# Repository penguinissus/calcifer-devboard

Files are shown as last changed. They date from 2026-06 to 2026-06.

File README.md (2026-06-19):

# Calcifer Devboard
Calcifer Devboard is a funny take on the RP2040 Devboard. It contains all of the basic components of what a devboard usually has like SRAM, processors, USB controllers, and breakout pins. The interesting twist on this devboard is that it is shaped like Calcifer, a character from Howl's Moving Castle.  
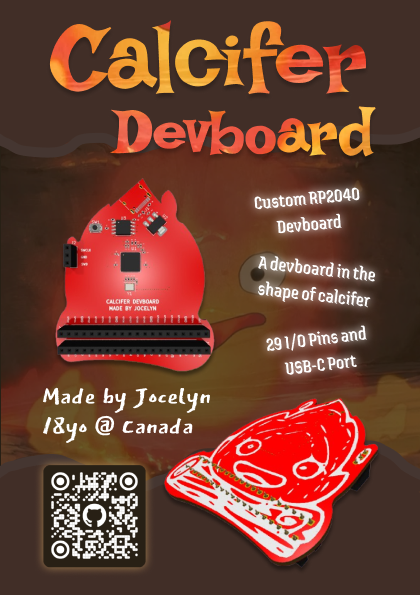
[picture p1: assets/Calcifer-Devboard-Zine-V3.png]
Zine
   

# Features
- USB-C Port  
- 12MHz Crystal Oscillator  
- 16mb Flash Storage
- 29 I/O Pins  

# Why did I make it
If you don't know the story behind Howl's Moving Castle, Calcifer is a fire demon that is trapped inside Howl's Castle and he powers and controls all of the magical things that the castle does. To me, this seemed parallel to what a devboard does in any electronics project, since a devboard is basically the heart and soul and would control all of the other components around it. 

# Diagrams
This schematic diagram looks the exact same as the guide from kaipereira.  
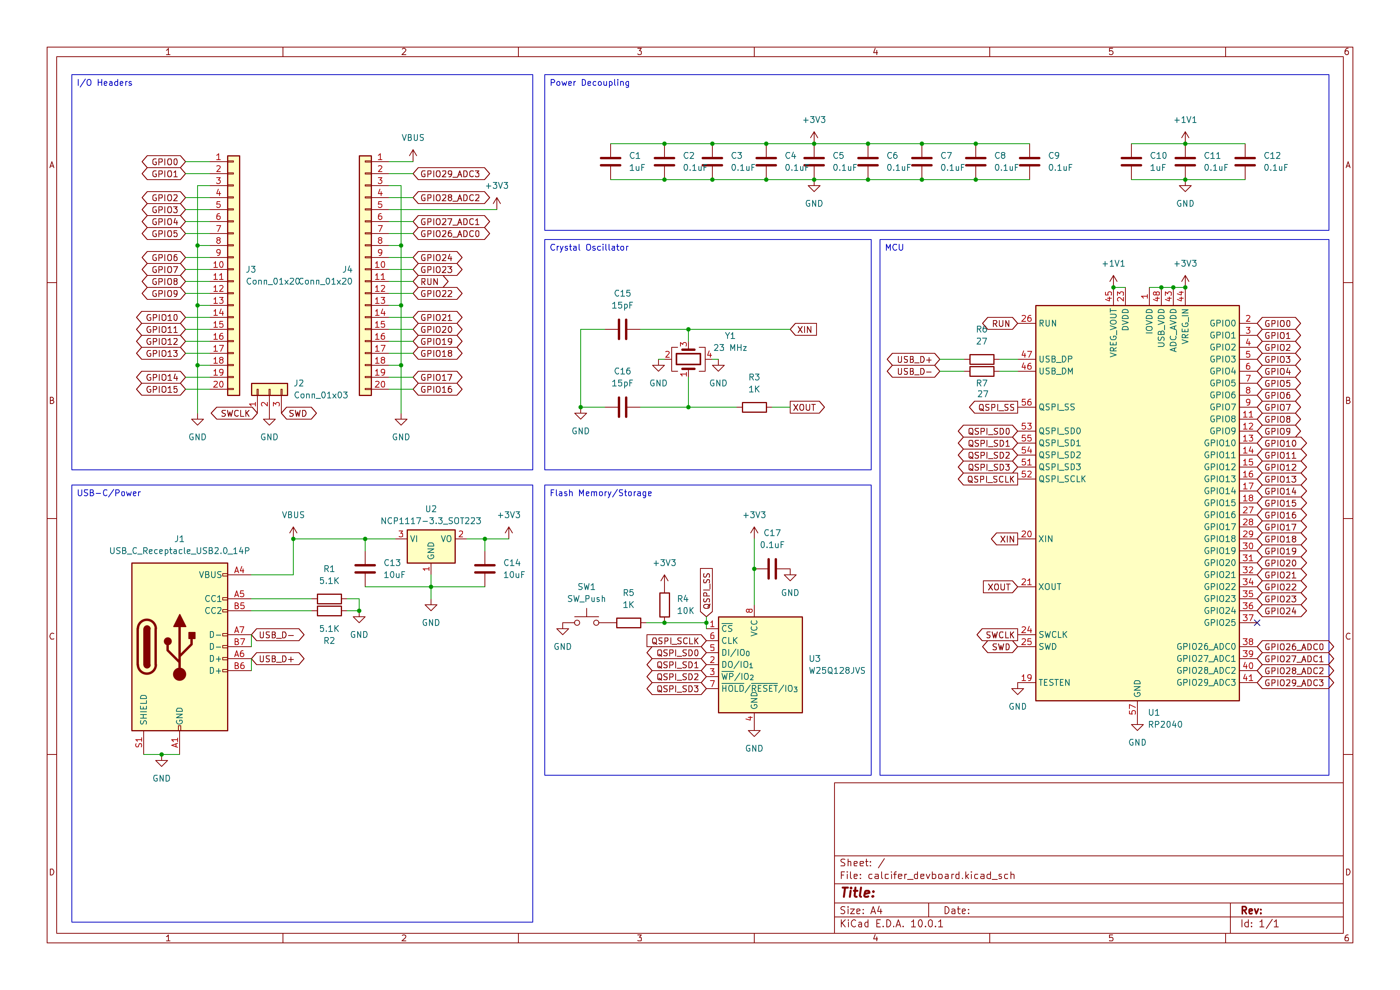
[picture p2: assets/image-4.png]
Schematic Diagram
  
This is what my devboard looked like in the PCB editor. You can see that it has the outline and silkscreen of calcifer on it.  
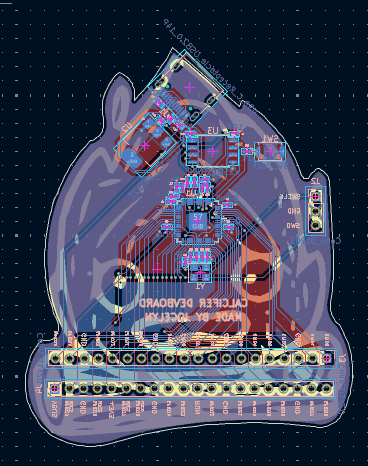
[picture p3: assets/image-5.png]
PCB Editor View
  
This is what the front of the PCB should look like when it is built properly. The frontside only shows a silkscreen of calcifer and is not obstructed by any components.  
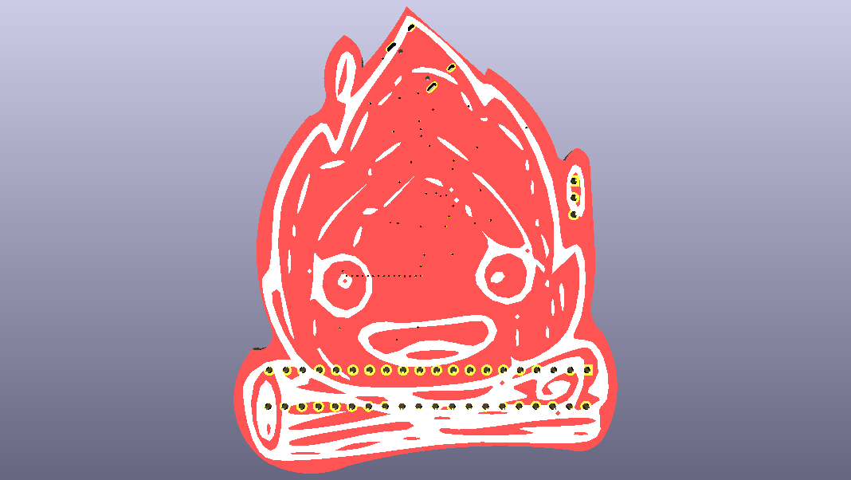
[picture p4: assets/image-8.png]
3D Model Front View
  
This is what the back of the PCB should look like. All of the components are on this side and all of the pins are clearly labeled. There is also a label saying this is made by me.  
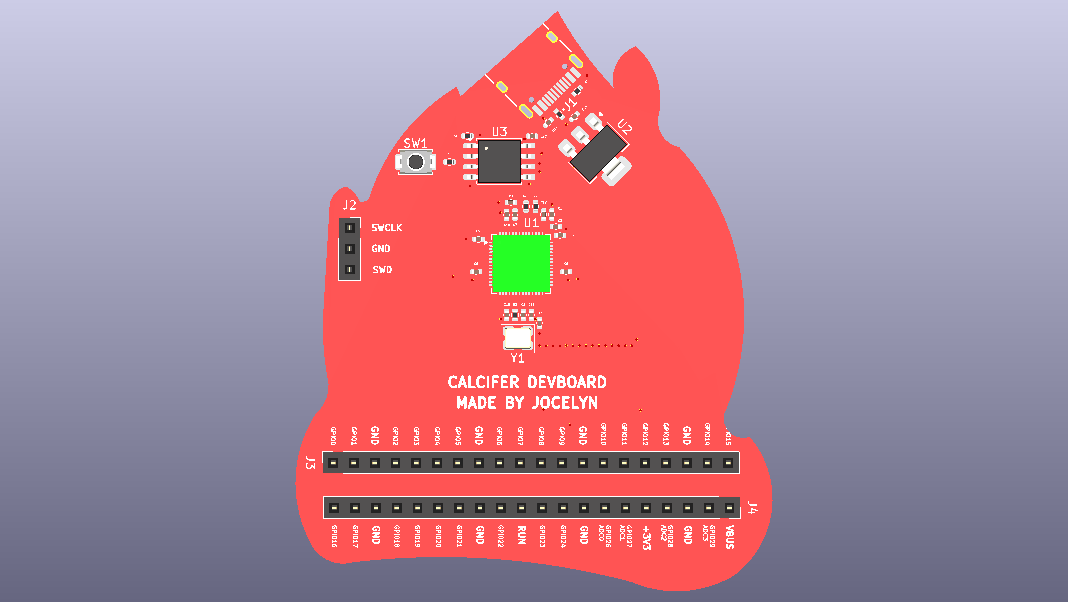
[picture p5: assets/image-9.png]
3D Model Back View
  

# Resource
This project is all thanks to [kaipereira's guide](https://github.com/KaiPereira/build-a-devboard/blob/master/README.md) on designing an RP2040 devboard. 

# How to use
This is just a devboard so there isn't really a step-by-step assembly or firmware isntructions.

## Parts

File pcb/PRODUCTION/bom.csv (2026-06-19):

Designator | Footprint | Quantity | Value | LCSC Part #
C1, C10 | 0402 | 2 | 1uF
C11, C12, C17, C2, C3, C4, C5, C6, C7, C8, C9 | 0402 | 11 | 0.1uF
C13, C14 | 0402 | 2 | 10uF
C15, C16 | 0402 | 2 | 15pF
J1 | USB_C_Receptacle_HRO_TYPE-C-31-M-12 | 1 | USB_C_Receptacle_USB2.0_14P
J2 | PinSocket_1x03_P2.54mm_Vertical | 1 | Conn_01x03
J3, J4 | PinSocket_1x20_P2.54mm_Vertical | 2 | Conn_01x20
R1, R2 | 0402 | 2 | 5.1K
R3, R5 | 0402 | 2 | 1K
R4 | 0402 | 1 | 10K
R6, R7 | 0402 | 2 | 27
SW1 | SW_Push_SPST_NO_Alps_SKRK | 1 | SW_Push
U1 | QFN-56-1EP_7x7mm_P0.4mm_EP3.2x3.2mm | 1 | RP2040
U2 | SOT-223-3_TabPin2 | 1 | NCP1117-3.3_SOT223
U3 | SOIC-8_5.3x5.3mm_P1.27mm | 1 | W25Q128JVS
Y1 | Crystal_SMD_3225-4Pin_3.2x2.5mm | 1 | 23 MHz

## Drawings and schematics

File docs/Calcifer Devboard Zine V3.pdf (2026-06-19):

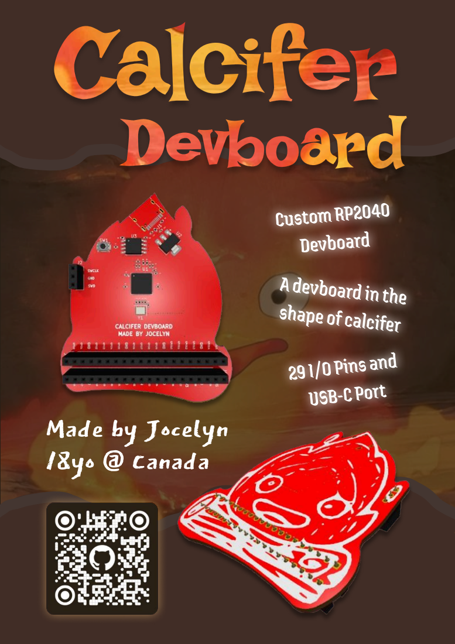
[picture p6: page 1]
Custom RP2040; Devboard; 29 I/O Pins and; USB-C Port

A devboard in the

shape of calcifer

Made by Jocelyn
18yo @ Canada

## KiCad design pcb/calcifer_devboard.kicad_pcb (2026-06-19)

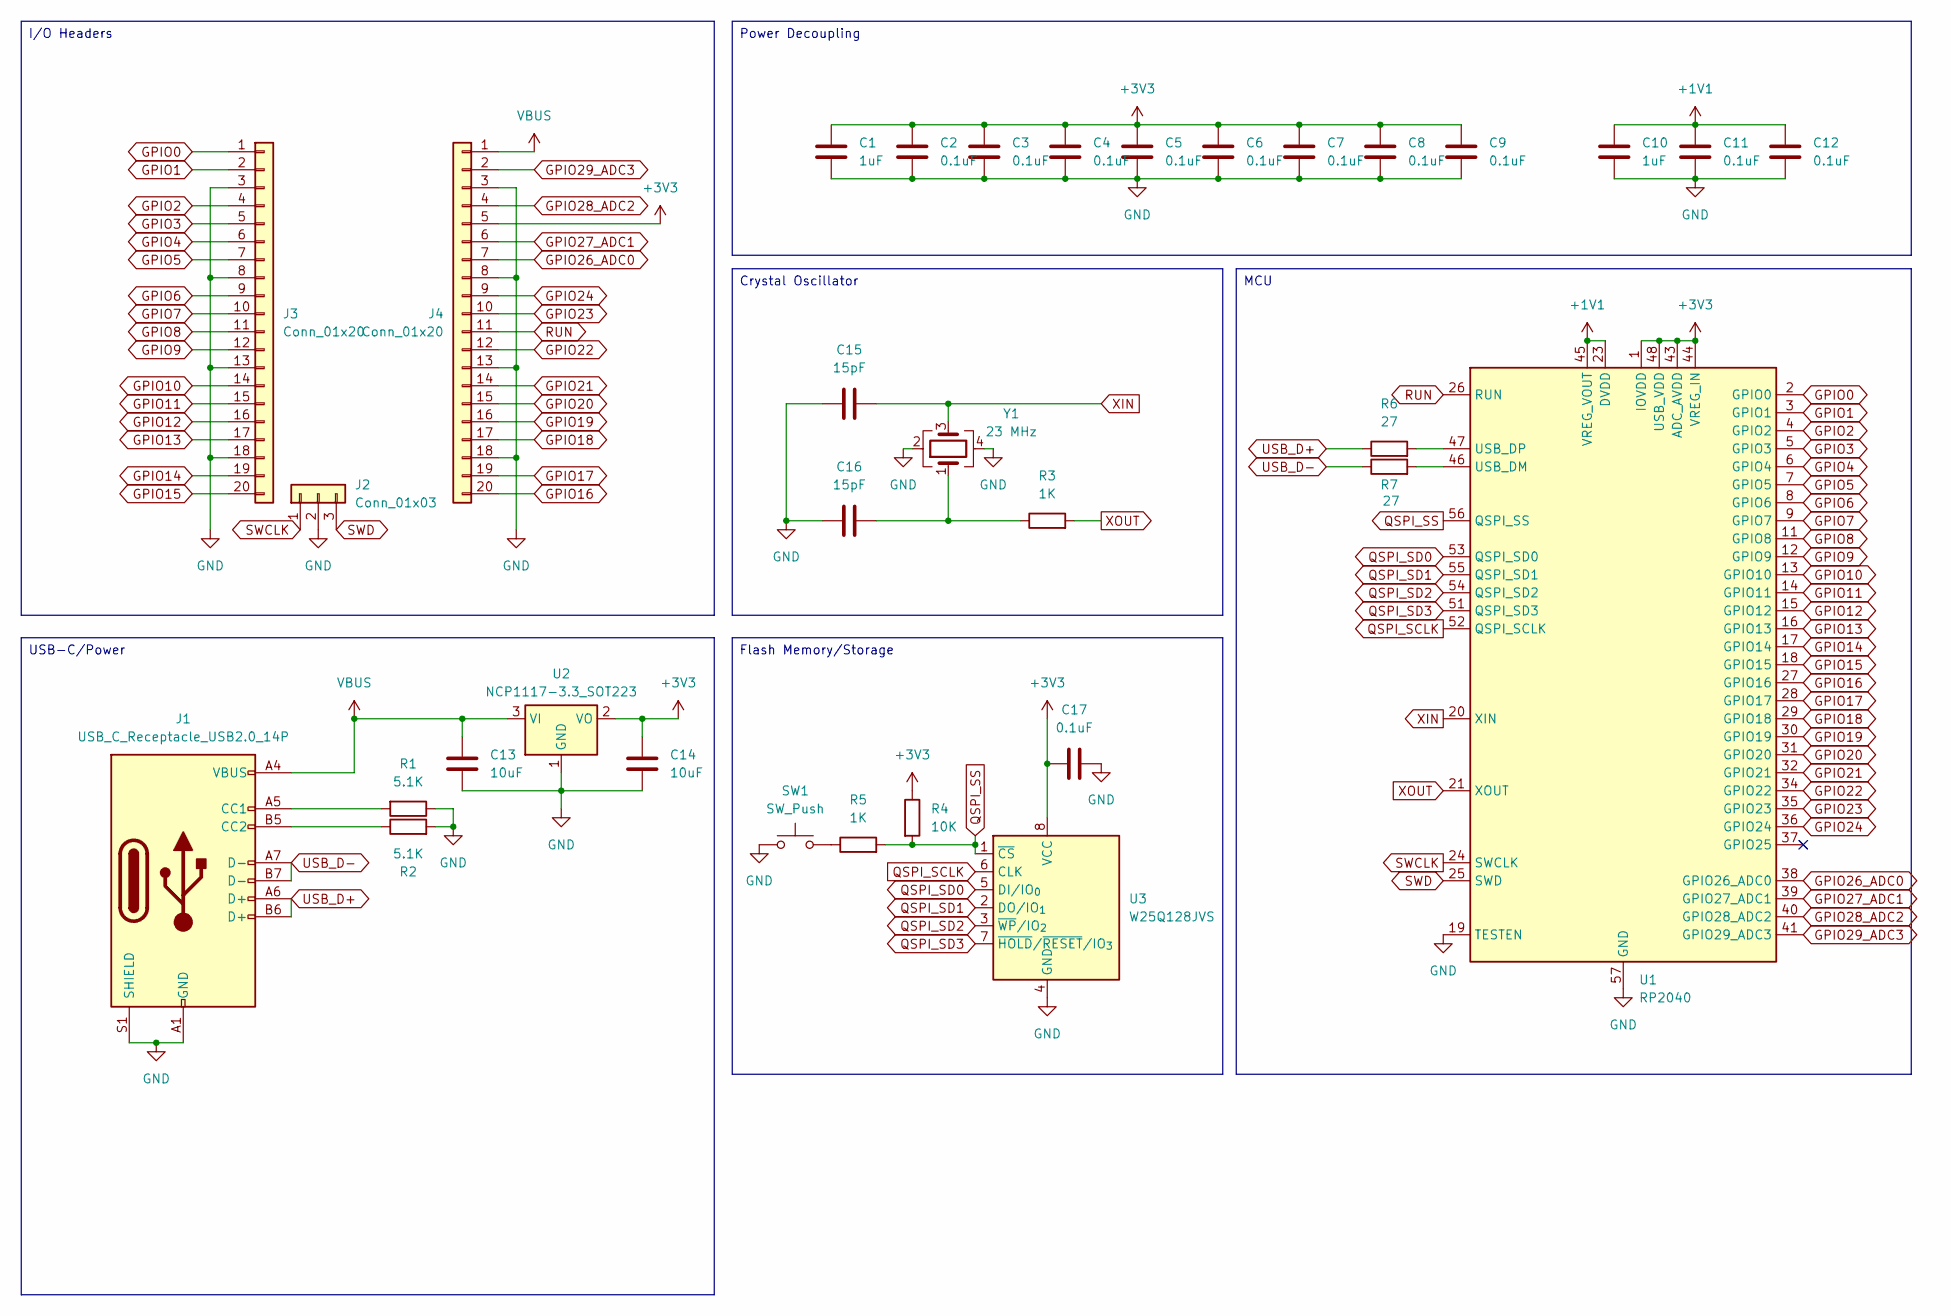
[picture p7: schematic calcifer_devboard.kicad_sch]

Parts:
C1, C10: 1uF; C_0402_1005Metric
C2, C3, C4, C5, C6, C7, C8, C9, C11, C12, C17: 0.1uF; C_0402_1005Metric
C13, C14: 10uF; C_0402_1005Metric
C15, C16: 15pF; C_0402_1005Metric
J1: USB_C_Receptacle_USB2.0_14P; USB_C_Receptacle_HRO_TYPE-C-31-M-12
J2: Conn_01x03; PinSocket_1x03_P2.54mm_Vertical
J3, J4: Conn_01x20; PinSocket_1x20_P2.54mm_Vertical
R1, R2: 5.1K; R_0402_1005Metric
R3, R5: 1K; R_0402_1005Metric
R4: 10K; R_0402_1005Metric
R6, R7: 27; R_0402_1005Metric
SW1: SW_Push; SW_Push_SPST_NO_Alps_SKRK
U1: RP2040; QFN-56-1EP_7x7mm_P0.4mm_EP3.2x3.2mm
U2: NCP1117-3.3_SOT223; SOT-223-3_TabPin2
U3: W25Q128JVS; SOIC-8_5.3x5.3mm_P1.27mm
Y1: 23 MHz; Crystal_SMD_3225-4Pin_3.2x2.5mm

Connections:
+1V1: C10.1, C11.1, C12.1, U1.23 (DVDD), U1.45 (VREG_VOUT), U1.50 (DVDD)
+3V3: C1.1, C2.1, C3.1, C4.1, C5.1, C6.1, C7.1, C8.1, C9.1, C14.1, C17.2, J4.5, R4.1, U1.1 (IOVDD), U1.10 (IOVDD), U1.22 (IOVDD), U1.33 (IOVDD), U1.42 (IOVDD), U1.43 (ADC_AVDD), U1.44 (VREG_IN), U1.48 (USB_VDD), U1.49 (IOVDD), U2.2 (VO), U3.8 (VCC)
GND: C1.2, C2.2, C3.2, C4.2, C5.2, C6.2, C7.2, C8.2, C9.2, C10.2, C11.2, C12.2, C13.2, C14.2, C15.1, C16.2, C17.1, J1.A1 (GND), J1.A12 (GND), J1.B1 (GND), J1.B12 (GND), J1.S1 (SHIELD), J2.2, J3.3, J3.8, J3.13, J3.18, J4.3, J4.8, J4.13, J4.18, R1.1, R2.2, SW1.1, U1.19 (TESTEN), U1.57 (GND), U2.1 (GND), U3.4 (GND), Y1.2, Y1.4
GPIO0: J3.1, U1.2 (GPIO0)
GPIO1: J3.2, U1.3 (GPIO1)
GPIO2: J3.4, U1.4 (GPIO2)
GPIO3: J3.5, U1.5 (GPIO3)
GPIO4: J3.6, U1.6 (GPIO4)
GPIO5: J3.7, U1.7 (GPIO5)
GPIO6: J3.9, U1.8 (GPIO6)
GPIO7: J3.10, U1.9 (GPIO7)
GPIO8: J3.11, U1.11 (GPIO8)
GPIO9: J3.12, U1.12 (GPIO9)
GPIO10: J3.14, U1.13 (GPIO10)
GPIO11: J3.15, U1.14 (GPIO11)
GPIO12: J3.16, U1.15 (GPIO12)
GPIO13: J3.17, U1.16 (GPIO13)
GPIO14: J3.19, U1.17 (GPIO14)
GPIO15: J3.20, U1.18 (GPIO15)
GPIO16: J4.20, U1.27 (GPIO16)
GPIO17: J4.19, U1.28 (GPIO17)
GPIO18: J4.17, U1.29 (GPIO18)
GPIO19: J4.16, U1.30 (GPIO19)
GPIO20: J4.15, U1.31 (GPIO20)
GPIO21: J4.14, U1.32 (GPIO21)
GPIO22: J4.12, U1.34 (GPIO22)
GPIO23: J4.10, U1.35 (GPIO23)
GPIO24: J4.9, U1.36 (GPIO24)
GPIO26_ADC0: J4.7, U1.38 (GPIO26_ADC0)
GPIO27_ADC1: J4.6, U1.39 (GPIO27_ADC1)
GPIO28_ADC2: J4.4, U1.40 (GPIO28_ADC2)
GPIO29_ADC3: J4.2, U1.41 (GPIO29_ADC3)
unnamed: C16.1, R3.1, Y1.1
unnamed: J1.A5 (CC1), R1.2
unnamed: J1.B5 (CC2), R2.1
unnamed: R5.1, SW1.2
unnamed: R7.2, U1.46 (USB_DM)
unnamed: R6.2, U1.47 (USB_DP)
QSPI_SCLK: U1.52 (QSPI_SCLK), U3.6 (CLK)
QSPI_SD0: U1.53 (QSPI_SD0), U3.5 (DI/IO_{0})
QSPI_SD1: U1.55 (QSPI_SD1), U3.2 (DO/IO_{1})
QSPI_SD2: U1.54 (QSPI_SD2), U3.3 (~WP/IO_{2})
QSPI_SD3: U1.51 (QSPI_SD3), U3.7 (~HOLD/~RESET/IO_{3})
QSPI_SS: R4.2, R5.2, U1.56 (QSPI_SS), U3.1 (~CS)
RUN: J4.11, U1.26 (RUN)
SWCLK: J2.1, U1.24 (SWCLK)
SWD: J2.3, U1.25 (SWD)
USB_D+: J1.A6 (D+), J1.B6 (D+), R6.1
USB_D-: J1.A7 (D-), J1.B7 (D-), R7.1
VBUS: C13.1, J1.A4 (VBUS), J1.A9 (VBUS), J1.B4 (VBUS), J1.B9 (VBUS), J4.1, U2.3 (VI)
XIN: C15.2, U1.20 (XIN), Y1.3
XOUT: R3.2, U1.21 (XOUT)

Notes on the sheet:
Flash Memory/Storage
Power Decoupling
I/O Headers
Crystal Oscillator
USB-C/Power
MCU

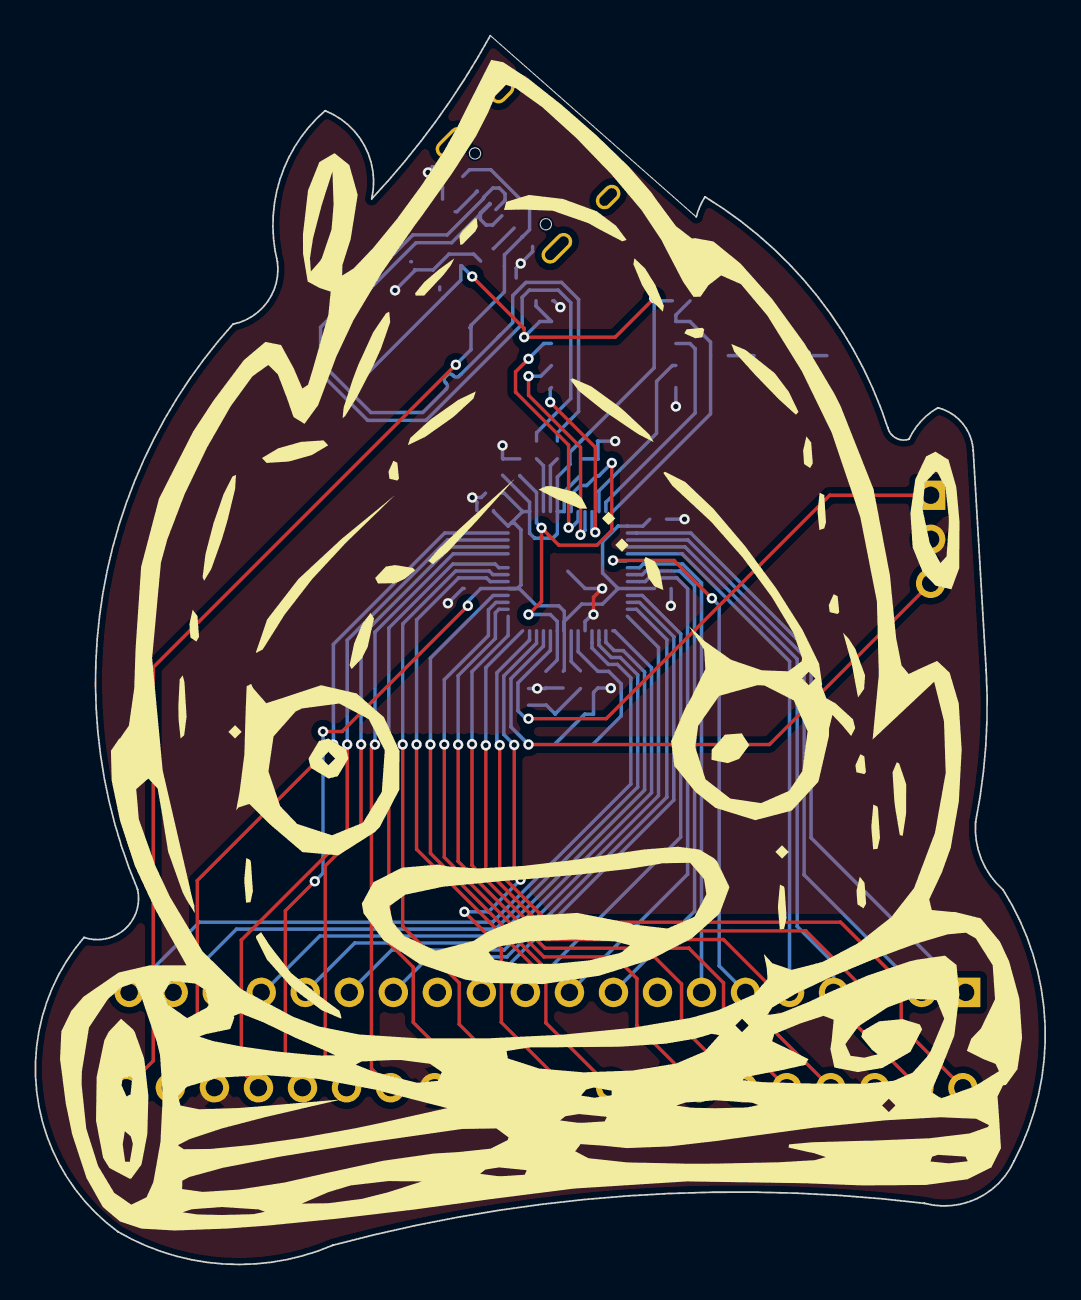
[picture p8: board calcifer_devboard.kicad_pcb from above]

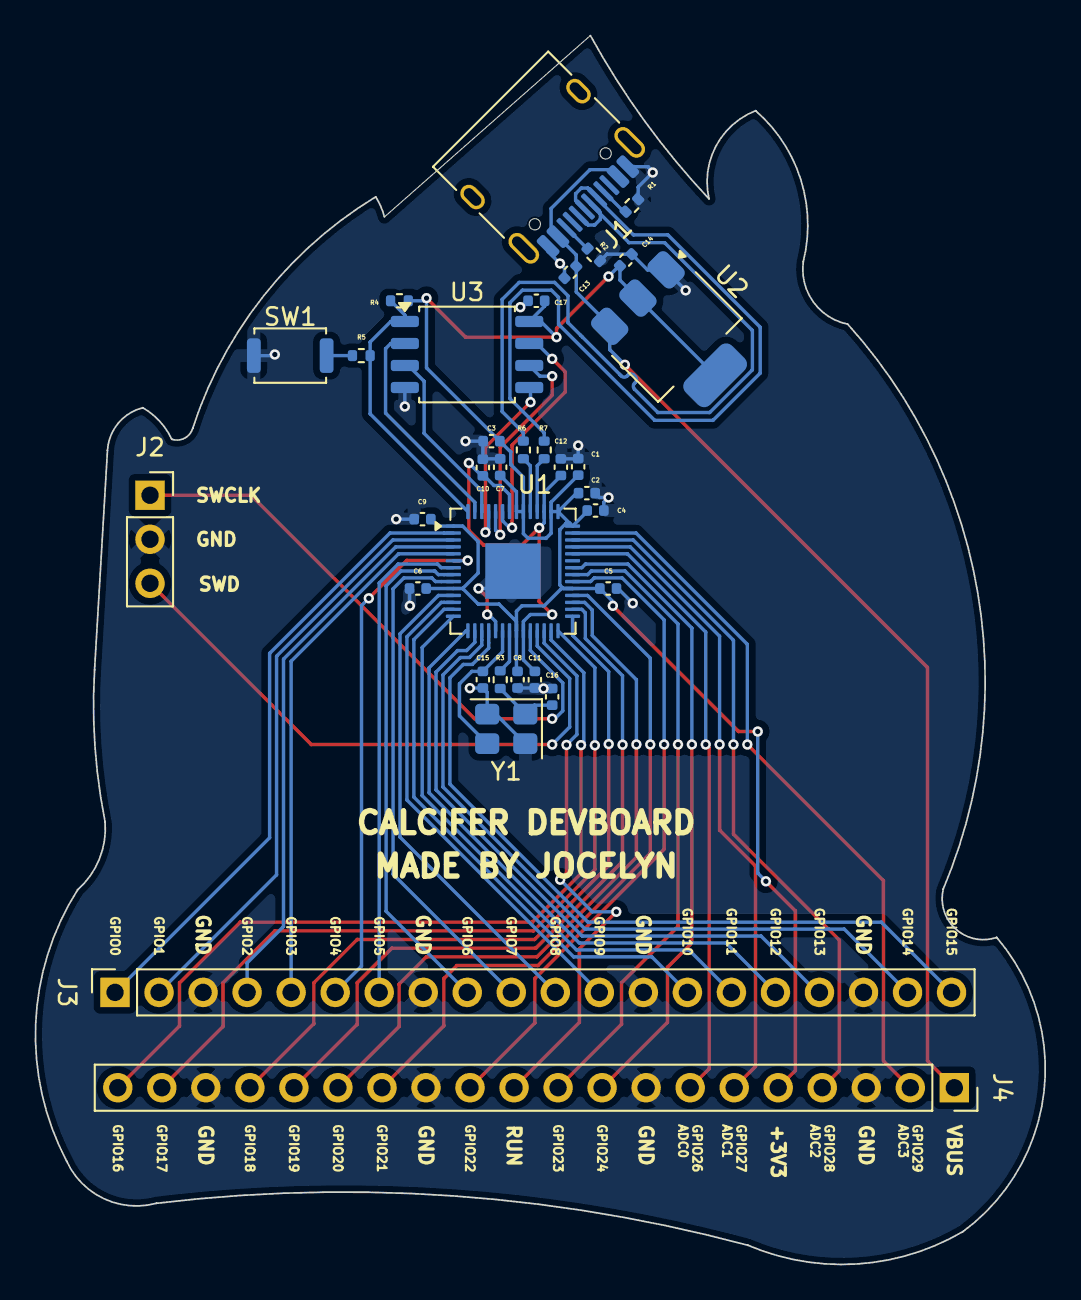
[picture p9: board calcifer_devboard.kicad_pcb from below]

Board: 2 copper layers, 58.2 x 70.9 mm, 33 parts (33 on the bottom side), 52 nets.

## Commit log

2026-06-17 retraced everything and finished readme
    [calcifer_devboard.kicad_pcb]
2026-06-18 Silkscreen update and complete README
    [calcifer_devboard.kicad_pcb]
2026-06-19 updated README and added production files
    [bom.csv, calcifer_devboard.kicad_pcb, designators.csv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]
2026-06-19 reorganize repository
    [calcifer_devboard.kicad_pcb, calcifer_devboard.kicad_sch]
2026-06-19 reorganize repo
    [bom.csv, calcifer_devboard.kicad_pcb, calcifer_devboard.kicad_sch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]
